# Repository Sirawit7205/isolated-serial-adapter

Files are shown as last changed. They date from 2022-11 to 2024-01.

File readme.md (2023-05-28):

# Isolated Quad Serial Adapter

This is an open-source KiCAD design files for a four-channel isolated USB-to-Serial adapter based on CH344Q IC from WCH.

## Pictures

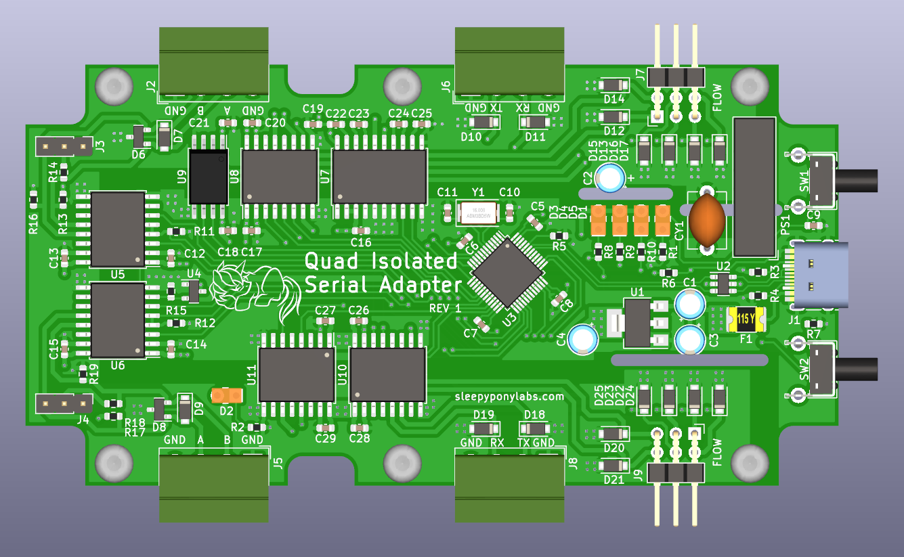
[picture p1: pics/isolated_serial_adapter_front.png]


## Features

This adapter is convenient when you want to connect multiple serial devices to your computer simultaneously, while also provides isolation between your computer and those devices.

- Four USB-to-Serial channels
	- CH344Q IC: Only one USB required to communicate with all fours channels at the same time at maximum speed of 6Mbps.
	- 1024 bytes of RX FIFO buffer and 512 bytes of TX FIFO buffer per channel.
	- Configured as 2x RS485, 1x RS232, and 1x 5V UART channels.
	- Modem flow control signals for RS232 and UART.
	- Auto direction control for RS485.
	- RS485 120 Ohms termination resistors (on/off)
- Full Isolation
	- All power and data signals are fully isolated between the USB and the serial side.
	- ADM2483 dedicated RS485 isolation IC.
	- ADM3251 dedicated RS232 isolated IC.
	- Digital Isolator ICs for other signals.
	- 1W 5V isolated DC/DC converter.
- Other Protection
	- TVS diodes on all signals line, including the USB.
- Intuitive Interfaces
	- USB Type-C Connector
	- Degson 3.5mm terminal blocks for serial channels
	- Pin header breakout for modem signals
	- RX/TX indicators
	- USB connection good indicator
	- Power indicators on both side of the isolation
	- USB reset and flow control mode buttons
	- Design to fit a Futurebox FB17 project box
	
## Revisions

We are currently at Revision 1. Changelog is below:

**Revision 1 (November 2022)**
 - Initial Design
 - U9 has wrong footprint (could still be soldered with some difficulties)

## What is provided

The goal of this repository is to enable you to build this on your own as easy as possible. **The schematics, PCB design, and an interactive BOM is provided.**

Hardware is licensed under `SPDX-License-Identifier: CERN-OHL-S-2.0`

Contains no software

Documentation is licensed under `SPDX-License-Identifier: CC-BY-SA-4.0`

## Ordering

You can export gerbers from this project and order the board yourself. You can also use the link below to directly order from Aisler.

https://aisler.net/p/QCJIQNDV

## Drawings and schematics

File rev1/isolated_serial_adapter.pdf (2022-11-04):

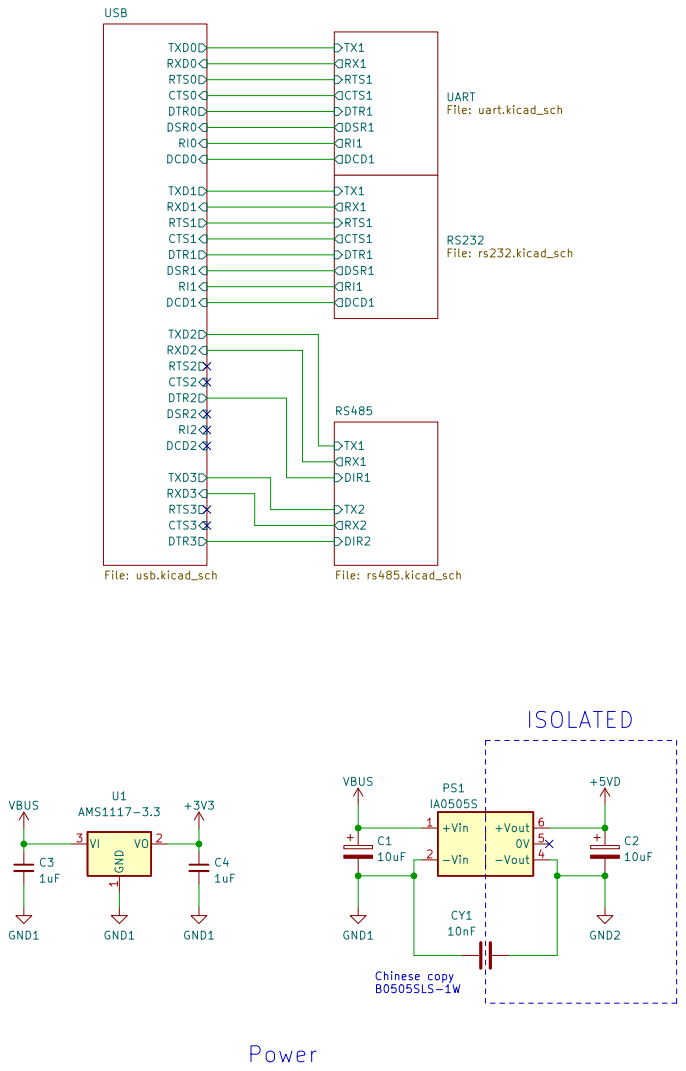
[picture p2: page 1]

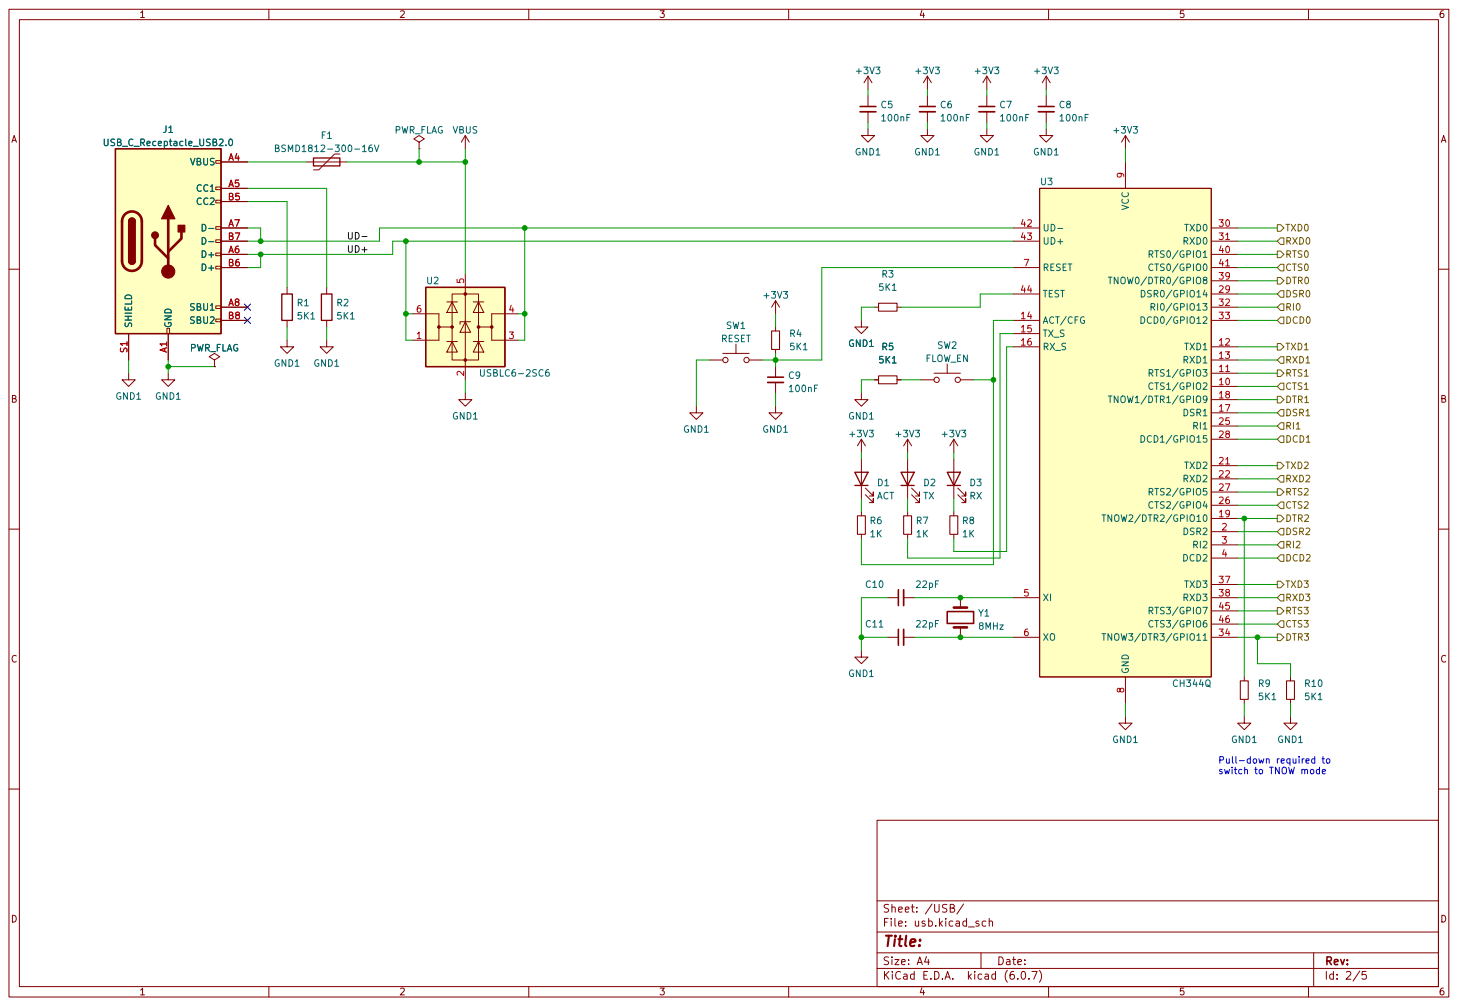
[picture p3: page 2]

switch to TNOW mode GND1 R5

File: usb.kicad_sch Sheet: /USB/
Id: 2/5 Title:

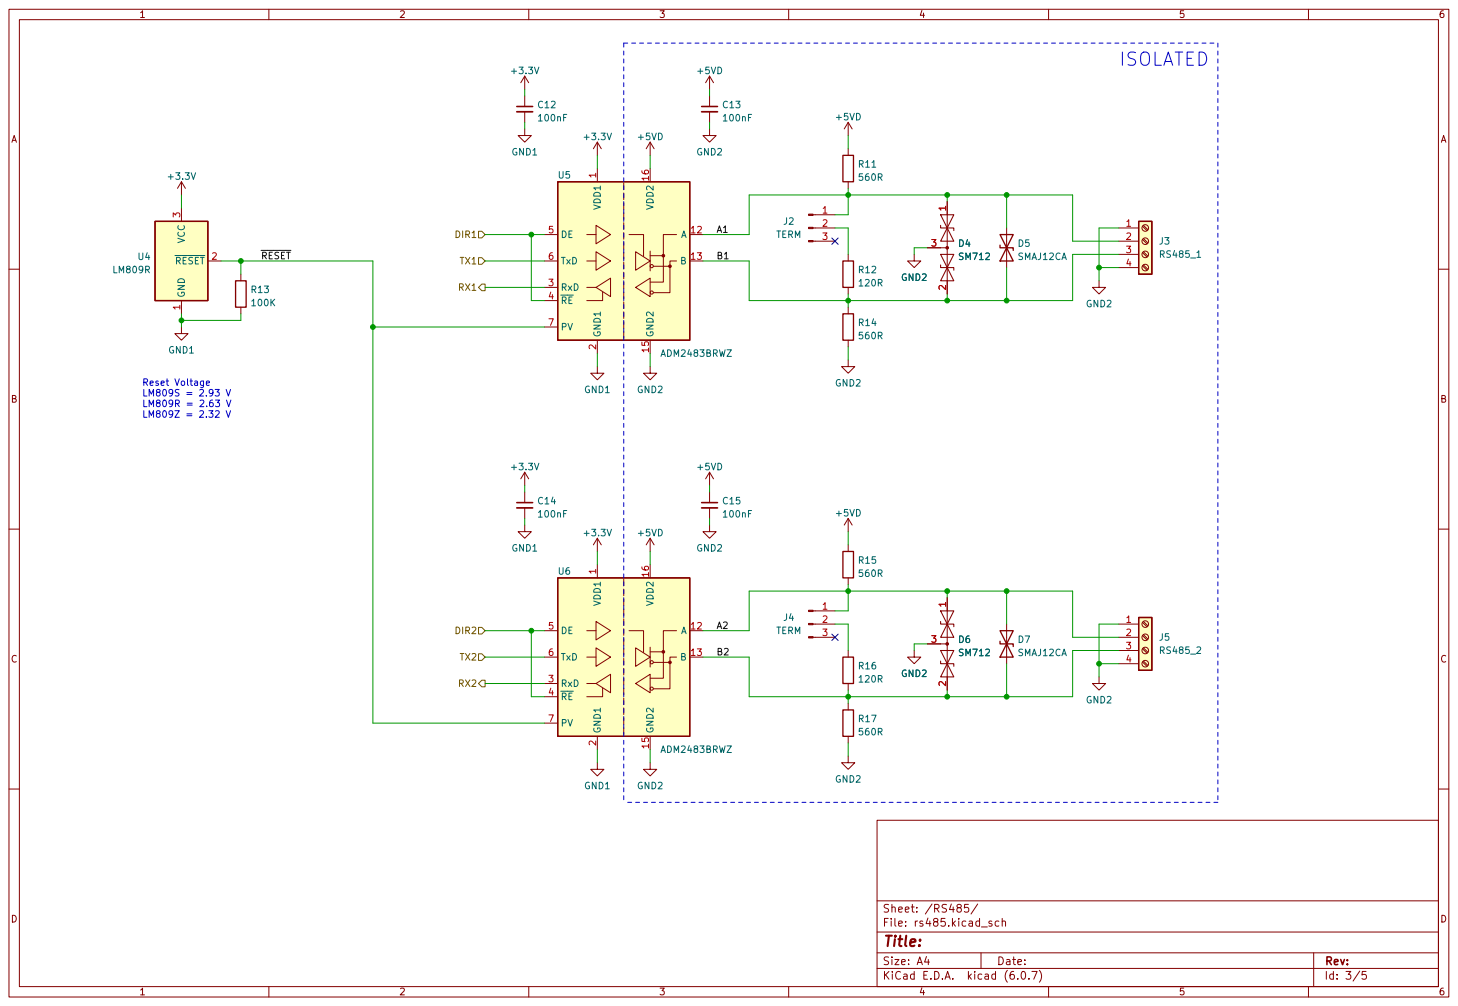
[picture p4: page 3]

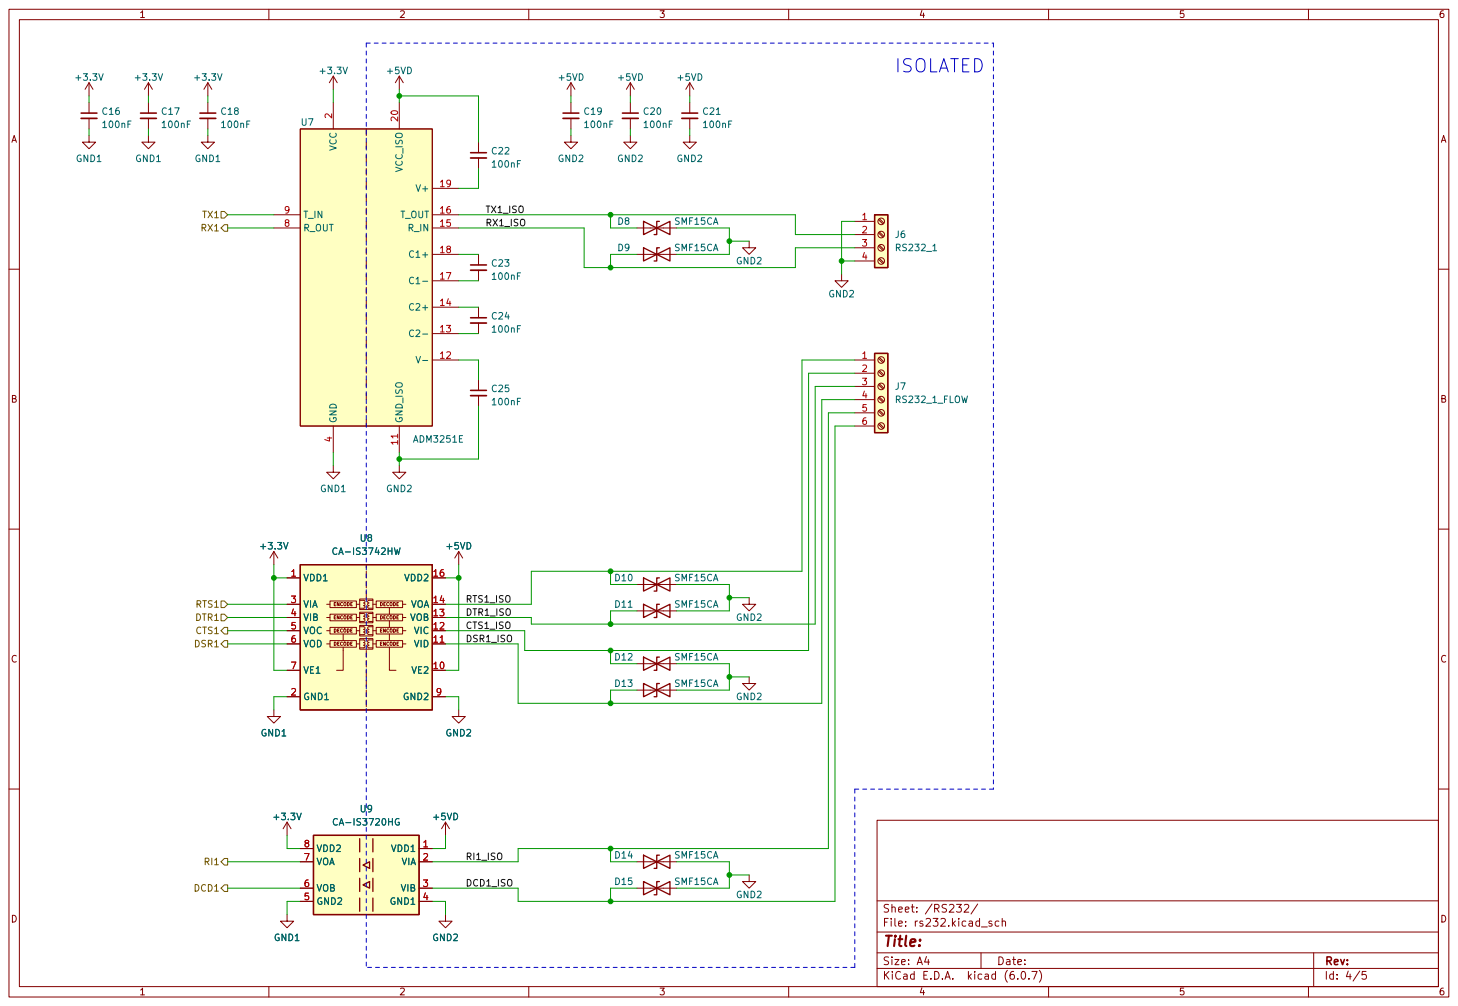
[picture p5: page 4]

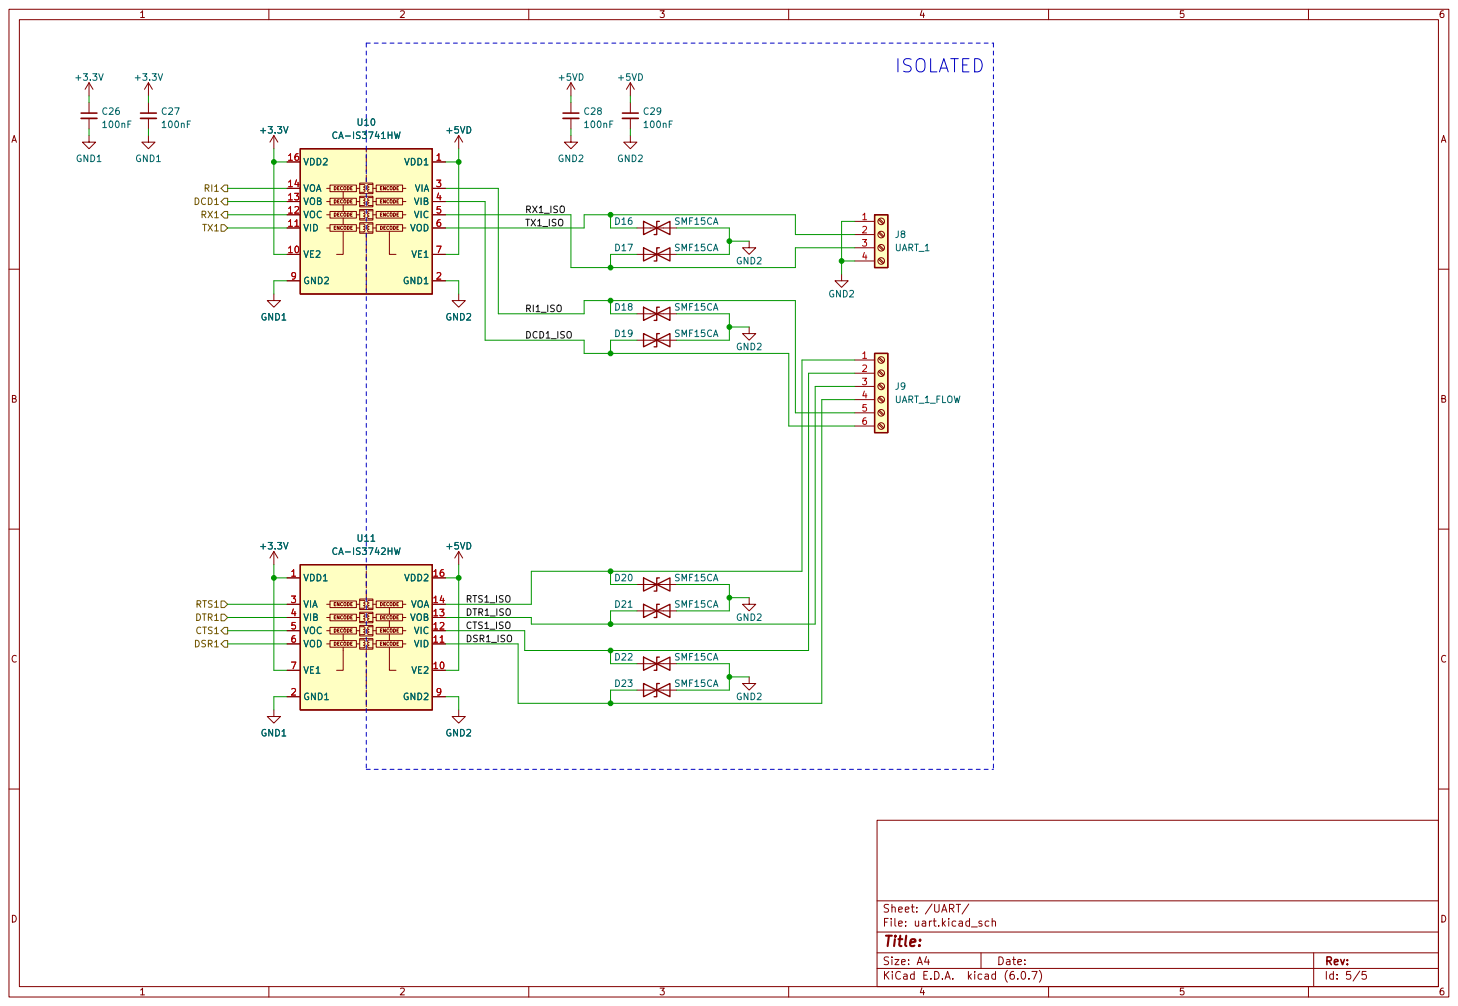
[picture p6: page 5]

DECODE DECODE

File: uart.kicad_sch Sheet: /UART/
Id: 5/5 Title:

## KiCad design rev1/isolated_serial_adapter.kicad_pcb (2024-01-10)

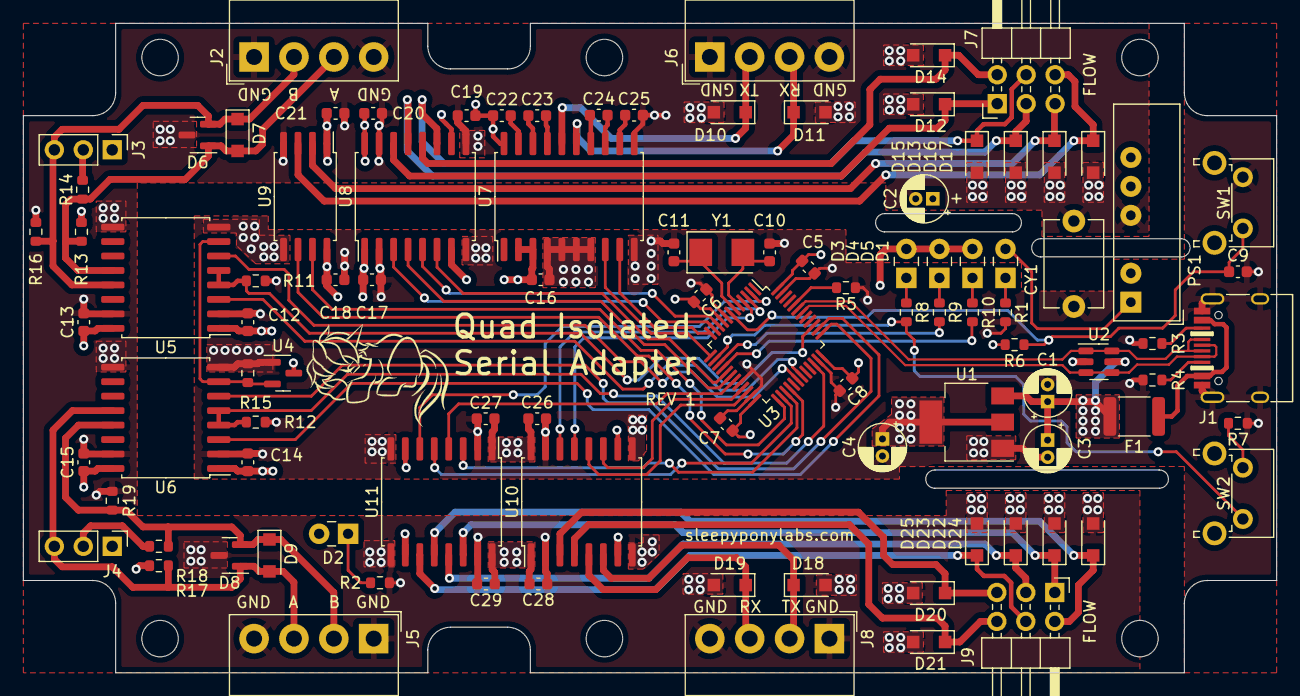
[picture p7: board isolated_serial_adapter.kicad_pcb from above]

Board: 4 copper layers, 110.0 x 57.0 mm, 105 parts (0 on the bottom side), 74 nets.

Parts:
C1, C2, C3, C4: 10uF; CP_Radial_D4.0mm_P1.50mm
C5, C6, C7, C8, C9, C12, C13, C14, C15, C16, C17, C18, C19, C20, C21, C22, C23, C24, C25, C26, C27, C28, C29: 100nF; C_0603_1608Metric
C10, C11: 22pF; C_0603_1608Metric
CY1: 1nF; C_Disc_D7.5mm_W5.0mm_P7.50mm
D1: PWR1; LED_Rectangular_W3.0mm_H2.0mm
D2: PWR2; LED_Rectangular_W3.0mm_H2.0mm
D3: ACT; LED_Rectangular_W3.0mm_H2.0mm
D4: TX; LED_Rectangular_W3.0mm_H2.0mm
D5: RX; LED_Rectangular_W3.0mm_H2.0mm
D6, D8: SM712; SOT-23
D7, D9: SMF12CA; D_SOD-123F
D10, D11, D12, D13, D14, D15, D16, D17, D18, D19, D20, D21, D22, D23, D24, D25: SMF15CA; D_SOD-123F
F1: BSMD1812-300-16V; Fuse_1812_4532Metric
H1, H2, H3, H4, H5, H6: M3; MountingHole_3.2mm_M3
J1: USB_C_Receptacle_USB2.0; USB_C_Receptacle_HRO_TYPE-C-31-M-12_NO_SBU
J2: RS485_1; TerminalBlock_Degson_1x04_P3.50mm_Horizontal
J3, J4: TERM; PinHeader_1x03_P2.54mm_Vertical
J5: RS485_2; TerminalBlock_Degson_1x04_P3.50mm_Horizontal
J6: RS232_1; TerminalBlock_Degson_1x04_P3.50mm_Horizontal
J7: RS232_1_FLOW; PinHeader_2x03_P2.54mm_Horizontal
J8: UART_1; TerminalBlock_Degson_1x04_P3.50mm_Horizontal
J9: UART_1_FLOW; PinHeader_2x03_P2.54mm_Horizontal
PS1: IA0505S; Converter_DCDC_XP_POWER-IAxxxxS_THT
R1, R2, R8, R9, R10: 1K; R_0603_1608Metric
R3, R4, R5, R6, R7, R11, R12: 5K1; R_0603_1608Metric
R13, R16, R17, R19: 680R; R_0603_1608Metric
R14, R18: 120R; R_0603_1608Metric
R15: 100K; R_0603_1608Metric
SW1: RESET; SW_Tactile_SPST_Angled_PTS645Vx83-2LFS
SW2: FLOW_EN; SW_Tactile_SPST_Angled_PTS645Vx83-2LFS
U1: AMS1117-3.3; SOT-223-3_TabPin2
U2: USBLC6-2SC6; SOT-23-6
U3: CH344Q; LQFP-48_7x7mm_P0.5mm
U4: LM809R; SOT-23
U5, U6: ADM2483BRWZ; SOIC-16W_7.5x10.3mm_P1.27mm
U7: ADM3251E; SOIC-20W_7.5x12.8mm_P1.27mm
U8, U11: CA-IS3742HW; SOIC-16W_7.5x10.3mm_P1.27mm
U9: CA-IS3720HG; SOIC-8_7.5x5.85mm_P1.27mm_modified
U10: CA-IS3741HW; SOIC-16W_7.5x10.3mm_P1.27mm
Y1: 8MHz; Crystal_SMD_5032-2Pin_5.0x3.2mm

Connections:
+3V3: C4.1, C5.1, C6.1, C7.1, C8.1, C12.1, C14.1, C16.1, C17.1, C18.1, C26.1, C27.1, D3.2 (A), D4.2 (A), D5.2 (A), R6.2, U1.2 (VO), U3.9 (VCC), U3.24 (VCC), U3.36 (VCC), U3.48 (VCC), U4.3 (VCC), U5.1 (VDD1), U6.1 (VDD1), U7.2 (VCC), U7.3 (VCC), U8.1 (VDD1), U8.7 (VE1), U9.8 (VDD2), U10.10 (VE2), U10.16 (VDD2), U11.1 (VDD1), U11.7 (VE1)
+5VD: C2.1, C13.1, C15.1, C19.1, C20.1, C21.1, C22.1, C28.1, C29.1, D2.2 (A), PS1.6 (+Vout), R13.1, R17.1, U5.16 (VDD2), U6.16 (VDD2), U7.20 (VCC_ISO), U8.10 (VE2), U8.16 (VDD2), U9.1 (VDD1), U10.1 (VDD1), U10.7 (VE1), U11.10 (VE2), U11.16 (VDD2)
/RS232/CTS1: U3.10 (CTS1/GPIO2), U8.5 (VOC)
/RS232/CTS1_ISO: D14.1 (A1), J7.2, U8.12 (VIC)
/RS232/DCD1: U3.28 (DCD1/GPIO15), U9.6 (VOB)
/RS232/DCD1_ISO: D17.1 (A1), J7.6, U9.3 (VIB)
/RS232/DSR1: U3.17 (DSR1), U8.6 (VOD)
/RS232/DSR1_ISO: D15.1 (A1), J7.4, U8.11 (VID)
/RS232/DTR1: U3.18 (TNOW1/DTR1/GPIO9), U8.4 (VIB)
/RS232/DTR1_ISO: D13.1 (A1), J7.3, U8.13 (VOB)
/RS232/RI1: U3.25 (RI1), U9.7 (VOA)
/RS232/RI1_ISO: D16.1 (A1), J7.5, U9.2 (VIA)
/RS232/RTS1: U3.11 (RTS1/GPIO3), U8.3 (VIA)
/RS232/RTS1_ISO: D12.1 (A1), J7.1, U8.14 (VOA)
/RS232/RX1: U3.13 (RXD1), U7.8 (R_OUT)
/RS232/RX1_ISO: D11.1 (A1), J6.3, U7.15 (R_IN)
/RS232/TX1: U3.12 (TXD1), U7.9 (T_IN)
/RS232/TX1_ISO: D10.1 (A1), J6.2, U7.16 (T_OUT)
/RS485/A0: D6.1 (A1), D7.2 (A2), J2.3, R13.2, R14.1, U5.12 (A)
/RS485/A3: D8.1 (A1), D9.2 (A2), J4.3, J5.3, R17.2, U6.12 (A)
/RS485/B0: D6.2 (A2), D7.1 (A1), J2.2, J3.3, R16.1, U5.13 (B)
/RS485/B3: D8.2 (A2), D9.1 (A1), J5.2, R18.2, R19.1, U6.13 (B)
/RS485/DIR0: R11.1, U3.39 (TNOW0/DTR0/GPIO8), U5.4 (~RE), U5.5 (DE)
/RS485/DIR3: R12.1, U3.34 (TNOW3/DTR3/GPIO11), U6.4 (~RE), U6.5 (DE)
/RS485/RX0: U3.31 (RXD0), U5.3 (RxD)
/RS485/RX3: U3.38 (RXD3), U6.3 (RxD)
/RS485/TX0: U3.30 (TXD0), U5.6 (TxD)
/RS485/TX3: U3.37 (TXD3), U6.6 (TxD)
/RS485/~RESET: R15.1, U4.2 (~RESET), U5.7 (PV), U6.7 (PV)
/UART/CTS2: U3.26 (CTS2/GPIO4), U11.5 (VOC)
/UART/CTS2_ISO: D24.1 (A1), J9.2, U11.12 (VIC)
/UART/DCD2: U3.4 (DCD2), U10.13 (VOB)
/UART/DCD2_ISO: D21.1 (A1), J9.6, U10.4 (VIB)
/UART/DSR2: U3.2 (DSR2), U11.6 (VOD)
/UART/DSR2_ISO: D25.1 (A1), J9.4, U11.11 (VID)
/UART/DTR2: U3.19 (TNOW2/DTR2/GPIO10), U11.4 (VIB)
/UART/DTR2_ISO: D23.1 (A1), J9.3, U11.13 (VOB)
/UART/RI2: U3.3 (RI2), U10.14 (VOA)
/UART/RI2_ISO: D20.1 (A1), J9.5, U10.3 (VIA)
/UART/RTS2: U3.27 (RTS2/GPIO5), U11.3 (VIA)
/UART/RTS2_ISO: D22.1 (A1), J9.1, U11.14 (VOA)
/UART/RX2: U3.22 (RXD2), U10.12 (VOC)
/UART/RX2_ISO: D19.1 (A1), J8.3, U10.5 (VIC)
/UART/TX2: U3.21 (TXD2), U10.11 (VID)
/UART/TX2_ISO: D18.1 (A1), J8.2, U10.6 (VOD)
/USB/ACT: R8.2, SW2.2, U3.14 (ACT/CFG)
/USB/RXS: R10.2, U3.16 (RX_S)
/USB/TXS: R9.2, U3.15 (TX_S)
/USB/UD+: J1.A6 (D+), J1.B6 (D+), U2.1 (I/O1), U2.6 (I/O1), U3.43 (UD+)
/USB/UD-: J1.A7 (D-), J1.B7 (D-), U2.3 (I/O2), U2.4 (I/O2), U3.42 (UD-)
GND: C1.2, C3.2, C4.2, C5.2, C6.2, C7.2, C8.2, C9.2, C10.1, C11.1, C12.2, C14.2, C16.2, C17.2, C18.2, C26.2, C27.2, CY1.1, J1.A1 (GND), J1.A12 (GND), J1.B1 (GND), J1.B12 (GND), J1.S1 (SHIELD), PS1.2 (-Vin), R1.2, R3.2, R4.2, R5.1, R7.1, R11.2, R12.2, R15.2, SW1.1, U1.1 (GND), U2.2 (GND), U3.8 (GND), U3.20 (GND), U3.23 (GND), U3.35 (GND), U3.47 (GND), U4.1 (GND), U5.2 (GND1), U5.8 (GND1), U6.2 (GND1), U6.8 (GND1), U7.4 (GND), U7.5 (GND), U7.6 (GND), U7.7 (GND), U7.10 (GND), U8.2 (GND1), U8.8 (GND1), U9.5 (GND2), U10.9 (GND2), U10.15 (GND2), U11.2 (GND1), U11.8 (GND1)
GND2: C2.2, C13.2, C15.2, C19.2, C20.2, C21.2, C25.2, C28.2, C29.2, CY1.2, D6.3 (common), D8.3 (common), D10.2 (A2), D11.2 (A2), D12.2 (A2), D13.2 (A2), D14.2 (A2), D15.2 (A2), D16.2 (A2), D17.2 (A2), D18.2 (A2), D19.2 (A2), D20.2 (A2), D21.2 (A2), D22.2 (A2), D23.2 (A2), D24.2 (A2), D25.2 (A2), J2.1, J2.4, J5.1, J5.4, J6.1, J6.4, J8.1, J8.4, PS1.4 (-Vout), R2.2, R16.2, R19.2, U5.9 (GND2), U5.15 (GND2), U6.9 (GND2), U6.15 (GND2), U7.11 (GND_ISO), U8.9 (GND2), U8.15 (GND2), U9.4 (GND1), U10.2 (GND1), U10.8 (GND1), U11.9 (GND2), U11.15 (GND2)
unnamed: C9.1, R6.1, SW1.2, U3.7 (RESET)
unnamed: C10.2, U3.5 (XI), Y1.2
unnamed: C11.2, U3.6 (XO), Y1.1
unnamed: C22.2, U7.19 (V+)
unnamed: C23.1, U7.18 (C1+)
unnamed: C23.2, U7.17 (C1-)
unnamed: C24.1, U7.14 (C2+)
unnamed: C24.2, U7.13 (C2-)
unnamed: C25.1, U7.12 (V-)
unnamed: D1.1 (K), R1.1
unnamed: D2.1 (K), R2.1
unnamed: D3.1 (K), R8.1
unnamed: D4.1 (K), R9.1
unnamed: D5.1 (K), R10.1
unnamed: F1.1, J1.A4 (VBUS), J1.A9 (VBUS), J1.B4 (VBUS), J1.B9 (VBUS)
unnamed: J1.A5 (CC1), R4.1
unnamed: J1.B5 (CC2), R3.1
unnamed: J3.2, R14.2
unnamed: J4.2, R18.1
unnamed: R5.2, U3.44 (TEST)
unnamed: R7.2, SW2.1
VBUS: C1.1, C3.1, D1.2 (A), F1.2, PS1.1 (+Vin), U1.3 (VI), U2.5 (VBUS)

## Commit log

2022-11-07 Fix incorrect standoff clearances
    [isolated_serial_adapter.kicad_pcb]
2022-11-07 Fix NPTH and edge milling dimensions
    [isolated_serial_adapter.kicad_pcb]
2024-01-10 Rearrange the repo
    [isolated_serial_adapter.kicad_pcb, isolated_serial_adapter.kicad_sch, rs232.kicad_sch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]
